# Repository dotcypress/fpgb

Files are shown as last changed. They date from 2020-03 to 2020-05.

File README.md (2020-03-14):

# Forth Programmable Breadboard

🚧 Work in progress. Don't try this at home. 🚧

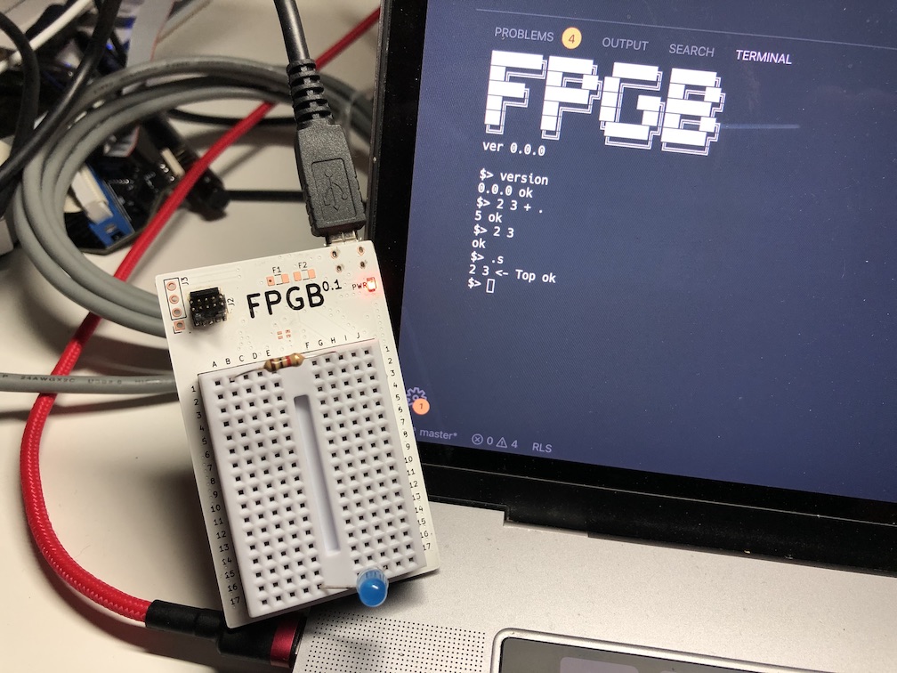
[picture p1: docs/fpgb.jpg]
Forth Programmable Breadboard


## Resources

- [Firmware](firmware/)
- [Schematics](docs/fpgb.pdf)
- [PCB(KiCad project)](pcb/)
- [Gerber files](docs/gerber)

## License

Licensed under either of

- Apache License, Version 2.0 ([LICENSE-APACHE](LICENSE-APACHE) or
  http://www.apache.org/licenses/LICENSE-2.0)
- MIT license ([LICENSE-MIT](LICENSE-MIT) or http://opensource.org/licenses/MIT)

at your option.

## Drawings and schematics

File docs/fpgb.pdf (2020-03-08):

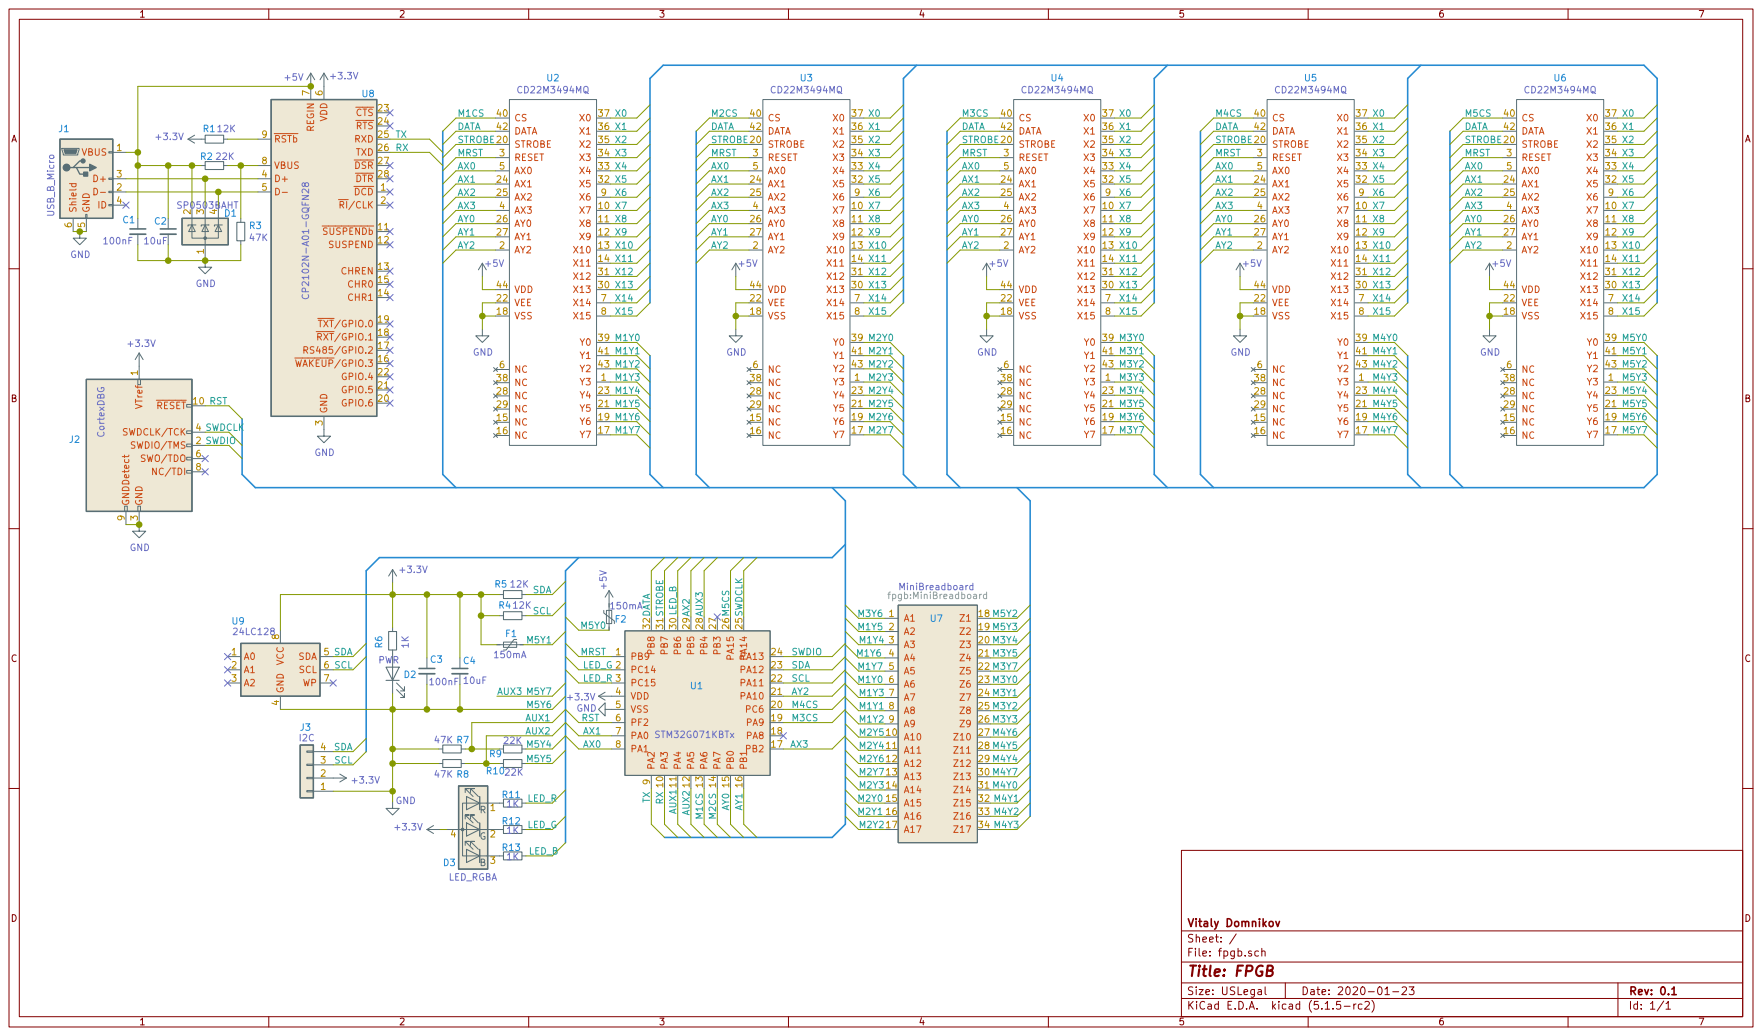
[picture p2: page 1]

7 VBUS 8 RSTb 9 U8 CP2102N-A01-GQFN28 VTref 1 RESET 10 SWDIO/TMS 2 GND

4D1 SP0503BAHT DCD 1 SUSPENDb 11 SUSPEND 12 CHREN 13 CHR1 14 CHR0 15 WAKEUP/GPIO.3 16 RS485/GPIO.2 17 RXT/GPIO.1 18 TXT/GPIO.0 19 RI/CLK 2 GPIO.6 20 GPIO.5 21 GPIO.4 22 CTS 23 RTS 24 RXD 25 TXD 26 DSR 27 DTR 28 GND

3 SWDCLK/TCK 4 SWO/TDO 6 NC/TDI 8 GNDDetect 9

4 SDA 5 SCL 6 WP 7 VCC

D Date: 2020-01-23 KiCad E.D.A. kicad (5.1.5-rc2)
File: fpgb.sch Sheet: / Vitaly Domnikov

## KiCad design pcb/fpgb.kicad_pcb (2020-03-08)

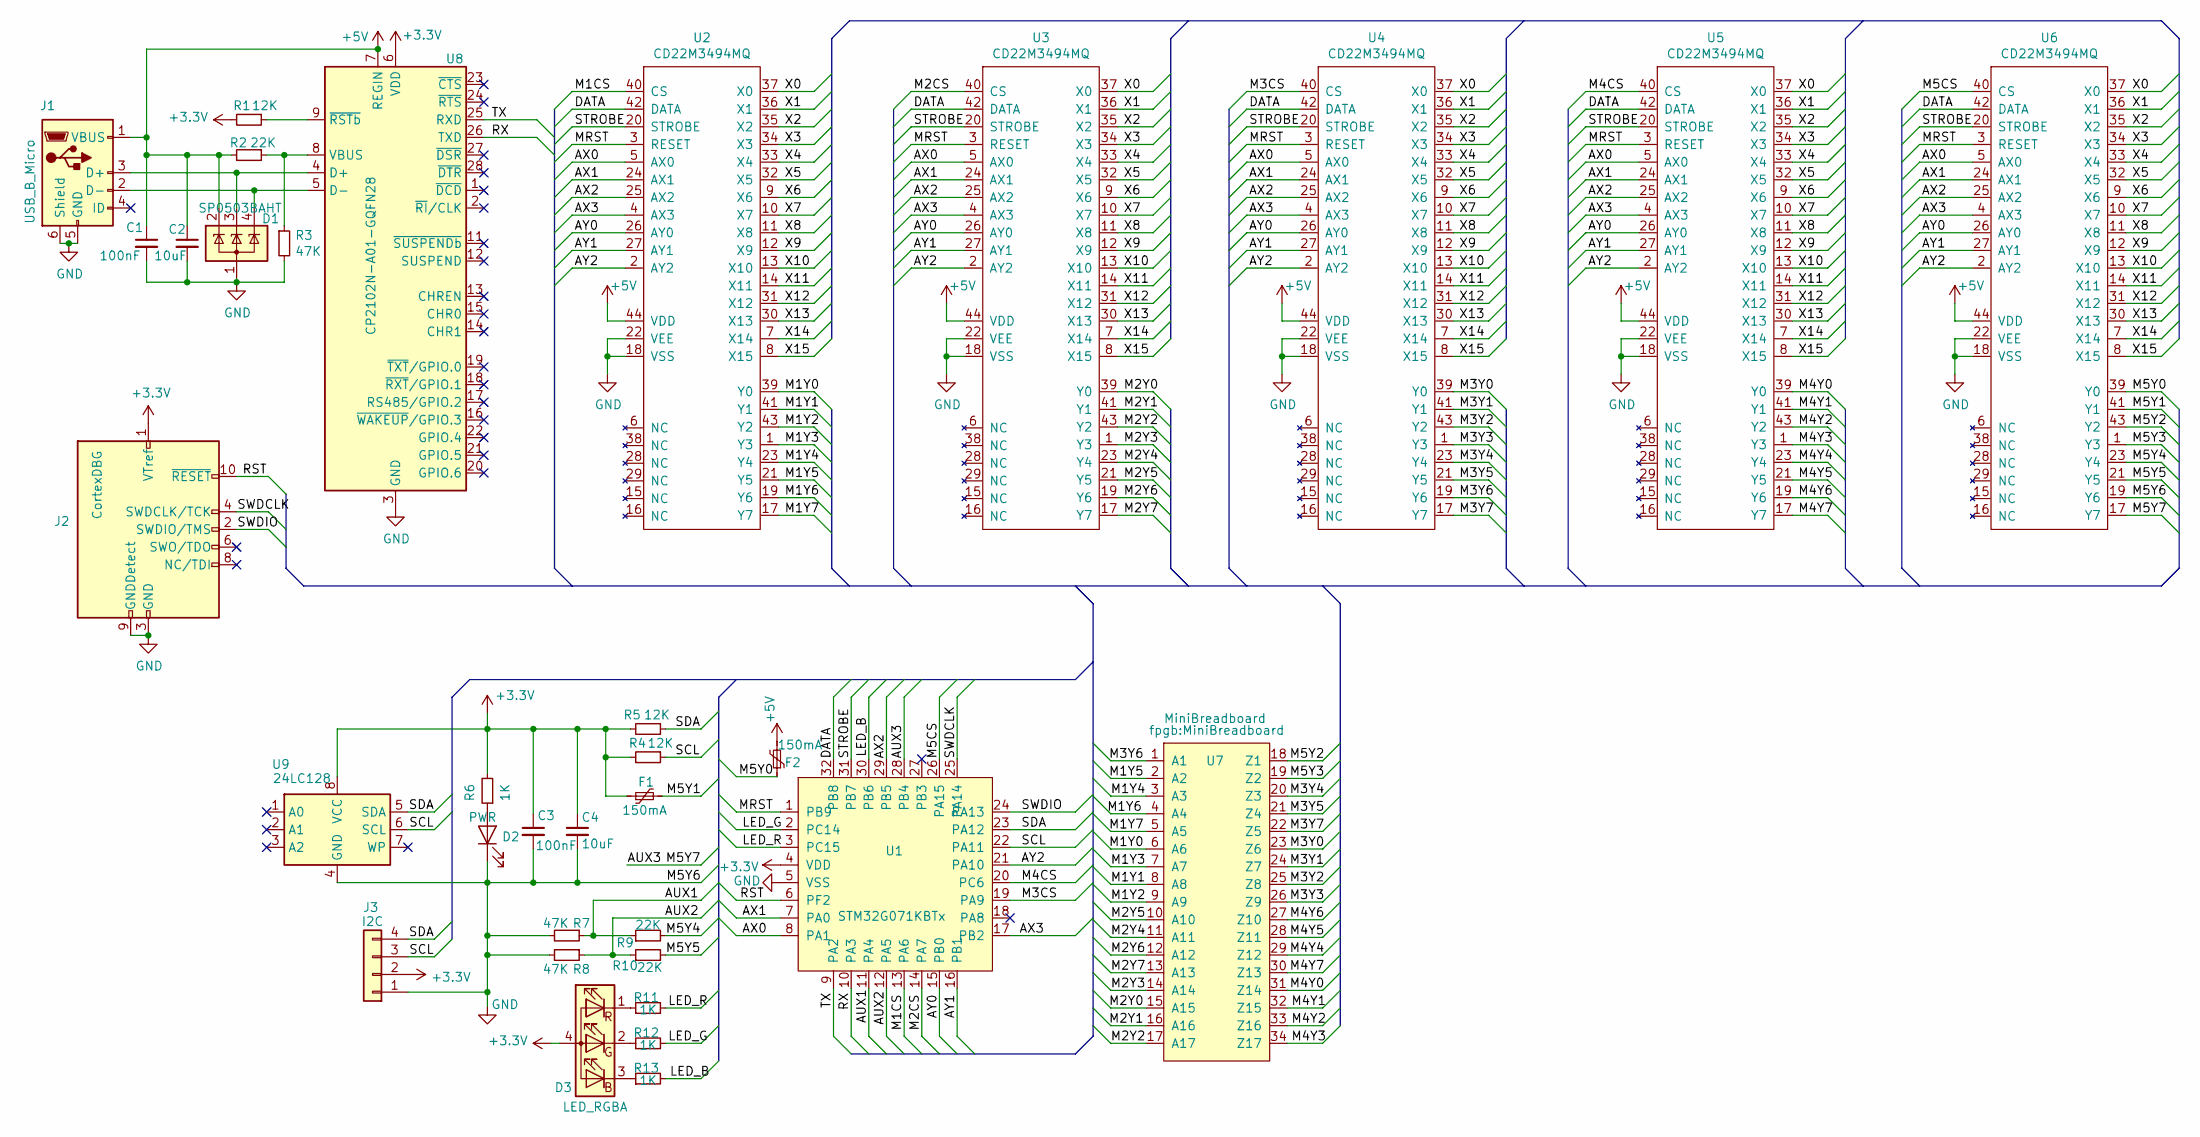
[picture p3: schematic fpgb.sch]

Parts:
C1, C3: 100nF; C_0603_1608Metric
C2, C4: 10uF; C_0603_1608Metric
D1: SP0503BAHT; SOT-143
D2: PWR; LED_0603_1608Metric
D3: LED_RGBA; LED_RGB_0606
F1, F2: 150mA; Fuse_1206_3216Metric
J1: USB_B_Micro; USB_Micro-B_Amphenol_10103594-0001LF_Horizontal
J2: CortexDBG; PinHeader_2x05_P1.27mm_Vertical_SMD
J3: I2C; PinSocket_1x04_P2.54mm_Vertical
R1, R4, R5: 12K; R_0603_1608Metric
R2, R9, R10: 22K; R_0603_1608Metric
R3, R7, R8: 47K; R_0603_1608Metric
R6, R11, R12, R13: 1K; R_0603_1608Metric
U1: STM32G071KBTx; LQFP-32_7x7mm_P0.8mm
U2, U3, U4, U5, U6: CD22M3494MQ; PLCC-44_16.6x16.6mm_P1.27mm
U7: MiniBreadboard
U8: CP2102N-A01-GQFN28; QFN-28-1EP_5x5mm_P0.5mm_EP3.35x3.35mm
U9: 24LC128; SOIC-8-1EP_3.9x4.9mm_P1.27mm_EP2.514x3.2mm

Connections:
+3V3: C3.1, C4.1, D3.4 (A), F1.1, J2.1 (VTref), J3.2, R1.2, R4.2, R5.2, R6.2, U1.4 (VDD), U8.6 (VDD), U9.8 (VCC)
+5V: C1.1, C2.1, D1.2 (K), F2.2, J1.1 (VBUS), R2.2, U2.44 (VDD), U3.44 (VDD), U4.44 (VDD), U5.44 (VDD), U6.44 (VDD), U8.7 (REGIN)
/AUX1: R7.1, R9.1, U1.11 (PA4)
/AUX2: R8.1, R10.1, U1.12 (PA5)
/AUX3: U1.28 (PB4), U6.17 (Y7)
/AX0: U1.8 (PA1), U2.5 (AX0), U3.5 (AX0), U4.5 (AX0), U5.5 (AX0), U6.5 (AX0)
/AX1: U1.7 (PA0), U2.24 (AX1), U3.24 (AX1), U4.24 (AX1), U5.24 (AX1), U6.24 (AX1)
/AX2: U1.29 (PB5), U2.25 (AX2), U3.25 (AX2), U4.25 (AX2), U5.25 (AX2), U6.25 (AX2)
/AX3: U1.17 (PB2), U2.4 (AX3), U3.4 (AX3), U4.4 (AX3), U5.4 (AX3), U6.4 (AX3)
/AY0: U1.15 (PB0), U2.26 (AY0), U3.26 (AY0), U4.26 (AY0), U5.26 (AY0), U6.26 (AY0)
/AY1: U1.16 (PB1), U2.27 (AY1), U3.27 (AY1), U4.27 (AY1), U5.27 (AY1), U6.27 (AY1)
/AY2: U1.21 (PA10), U2.2 (AY2), U3.2 (AY2), U4.2 (AY2), U5.2 (AY2), U6.2 (AY2)
/DATA: U1.32 (PB8), U2.42 (DATA), U3.42 (DATA), U4.42 (DATA), U5.42 (DATA), U6.42 (DATA)
/LED_B: R13.2, U1.30 (PB6)
/LED_G: R12.2, U1.2 (PC14)
/LED_R: R11.2, U1.3 (PC15)
/M1CS: U1.13 (PA6), U2.40 (CS)
/M1Y0: U2.39 (Y0), U7.6 (A6)
/M1Y1: U2.41 (Y1), U7.8 (A8)
/M1Y2: U2.43 (Y2), U7.9 (A9)
/M1Y3: U2.1 (Y3), U7.7 (A7)
/M1Y4: U2.23 (Y4), U7.3 (A3)
/M1Y5: U2.21 (Y5), U7.2 (A2)
/M1Y6: U2.19 (Y6), U7.4 (A4)
/M1Y7: U2.17 (Y7), U7.5 (A5)
/M2CS: U1.14 (PA7), U3.40 (CS)
/M2Y0: U3.39 (Y0), U7.15 (A15)
/M2Y1: U3.41 (Y1), U7.16 (A16)
/M2Y2: U3.43 (Y2), U7.17 (A17)
/M2Y3: U3.1 (Y3), U7.14 (A14)
/M2Y4: U3.23 (Y4), U7.11 (A11)
/M2Y5: U3.21 (Y5), U7.10 (A10)
/M2Y6: U3.19 (Y6), U7.12 (A12)
/M2Y7: U3.17 (Y7), U7.13 (A13)
/M3CS: U1.19 (PA9), U4.40 (CS)
/M3Y0: U4.39 (Y0), U7.23 (Z6)
/M3Y1: U4.41 (Y1), U7.24 (Z7)
/M3Y2: U4.43 (Y2), U7.25 (Z8)
/M3Y3: U4.1 (Y3), U7.26 (Z9)
/M3Y4: U4.23 (Y4), U7.20 (Z3)
/M3Y5: U4.21 (Y5), U7.21 (Z4)
/M3Y6: U4.19 (Y6), U7.1 (A1)
/M3Y7: U4.17 (Y7), U7.22 (Z5)
/M4CS: U1.20 (PC6), U5.40 (CS)
/M4Y0: U5.39 (Y0), U7.31 (Z14)
/M4Y1: U5.41 (Y1), U7.32 (Z15)
/M4Y2: U5.43 (Y2), U7.33 (Z16)
/M4Y3: U5.1 (Y3), U7.34 (Z17)
/M4Y4: U5.23 (Y4), U7.29 (Z12)
/M4Y5: U5.21 (Y5), U7.28 (Z11)
/M4Y6: U5.19 (Y6), U7.27 (Z10)
/M4Y7: U5.17 (Y7), U7.30 (Z13)
/M5CS: U1.26 (PA15), U6.40 (CS)
/M5Y0: F2.1, U6.39 (Y0)
/M5Y1: F1.2, U6.41 (Y1)
/M5Y2: U6.43 (Y2), U7.18 (Z1)
/M5Y3: U6.1 (Y3), U7.19 (Z2)
/M5Y4: R9.2, U6.23 (Y4)
/M5Y5: R10.2, U6.21 (Y5)
/MRST: U1.1 (PB9), U2.3 (RESET), U3.3 (RESET), U4.3 (RESET), U5.3 (RESET), U6.3 (RESET)
/RST: J2.10 (~RESET~), U1.6 (PF2)
/RX: U1.10 (PA3), U8.26 (TXD)
/SCL: J3.3, R4.1, U1.22 (PA11), U9.6 (SCL)
/SDA: J3.4, R5.1, U1.23 (PA12), U9.5 (SDA)
/STROBE: U1.31 (PB7), U2.20 (STROBE), U3.20 (STROBE), U4.20 (STROBE), U5.20 (STROBE), U6.20 (STROBE)
/SWDCLK: J2.4 (SWDCLK/TCK), U1.25 (PA14)
/SWDIO: J2.2 (SWDIO/TMS), U1.24 (PA13)
/TX: U1.9 (PA2), U8.25 (RXD)
/X0: U2.37 (X0), U3.37 (X0), U4.37 (X0), U5.37 (X0), U6.37 (X0)
/X1: U2.36 (X1), U3.36 (X1), U4.36 (X1), U5.36 (X1), U6.36 (X1)
/X2: U2.35 (X2), U3.35 (X2), U4.35 (X2), U5.35 (X2), U6.35 (X2)
/X3: U2.34 (X3), U3.34 (X3), U4.34 (X3), U5.34 (X3), U6.34 (X3)
/X4: U2.33 (X4), U3.33 (X4), U4.33 (X4), U5.33 (X4), U6.33 (X4)
/X5: U2.32 (X5), U3.32 (X5), U4.32 (X5), U5.32 (X5), U6.32 (X5)
/X6: U2.9 (X6), U3.9 (X6), U4.9 (X6), U5.9 (X6), U6.9 (X6)
/X7: U2.10 (X7), U3.10 (X7), U4.10 (X7), U5.10 (X7), U6.10 (X7)
/X8: U2.11 (X8), U3.11 (X8), U4.11 (X8), U5.11 (X8), U6.11 (X8)
/X9: U2.12 (X9), U3.12 (X9), U4.12 (X9), U5.12 (X9), U6.12 (X9)
/X10: U2.13 (X10), U3.13 (X10), U4.13 (X10), U5.13 (X10), U6.13 (X10)
/X11: U2.14 (X11), U3.14 (X11), U4.14 (X11), U5.14 (X11), U6.14 (X11)
/X12: U2.31 (X12), U3.31 (X12), U4.31 (X12), U5.31 (X12), U6.31 (X12)
/X13: U2.30 (X13), U3.30 (X13), U4.30 (X13), U5.30 (X13), U6.30 (X13)
/X14: U2.7 (X14), U3.7 (X14), U4.7 (X14), U5.7 (X14), U6.7 (X14)
/X15: U2.8 (X15), U3.8 (X15), U4.8 (X15), U5.8 (X15), U6.8 (X15)
GND: C1.2, C2.2, C3.2, C4.2, D1.1 (A), D2.1 (K), J1.5 (GND), J1.6 (Shield), J2.3 (GND), J2.5 (GND), J2.9 (GNDDetect), J3.1, R3.2, R7.2, R8.2, U1.5 (VSS), U2.18 (VSS), U2.22 (VEE), U3.18 (VSS), U3.22 (VEE), U4.18 (VSS), U4.22 (VEE), U5.18 (VSS), U5.22 (VEE), U6.18 (VSS), U6.19 (Y6), U6.22 (VEE), U8.3 (GND), U8.29 (GND), U9.4 (GND)
unnamed: D1.3 (K), J1.3 (D+), U8.4 (D+)
unnamed: D1.4 (K), J1.2 (D-), U8.5 (D-)
unnamed: D2.2 (A), R6.1
unnamed: D3.1 (RK), R11.1
unnamed: D3.2 (GK), R12.1
unnamed: D3.3 (BK), R13.1
unnamed: R1.1, U8.9 (~RSTb)
unnamed: R2.1, R3.1, U8.8 (VBUS)

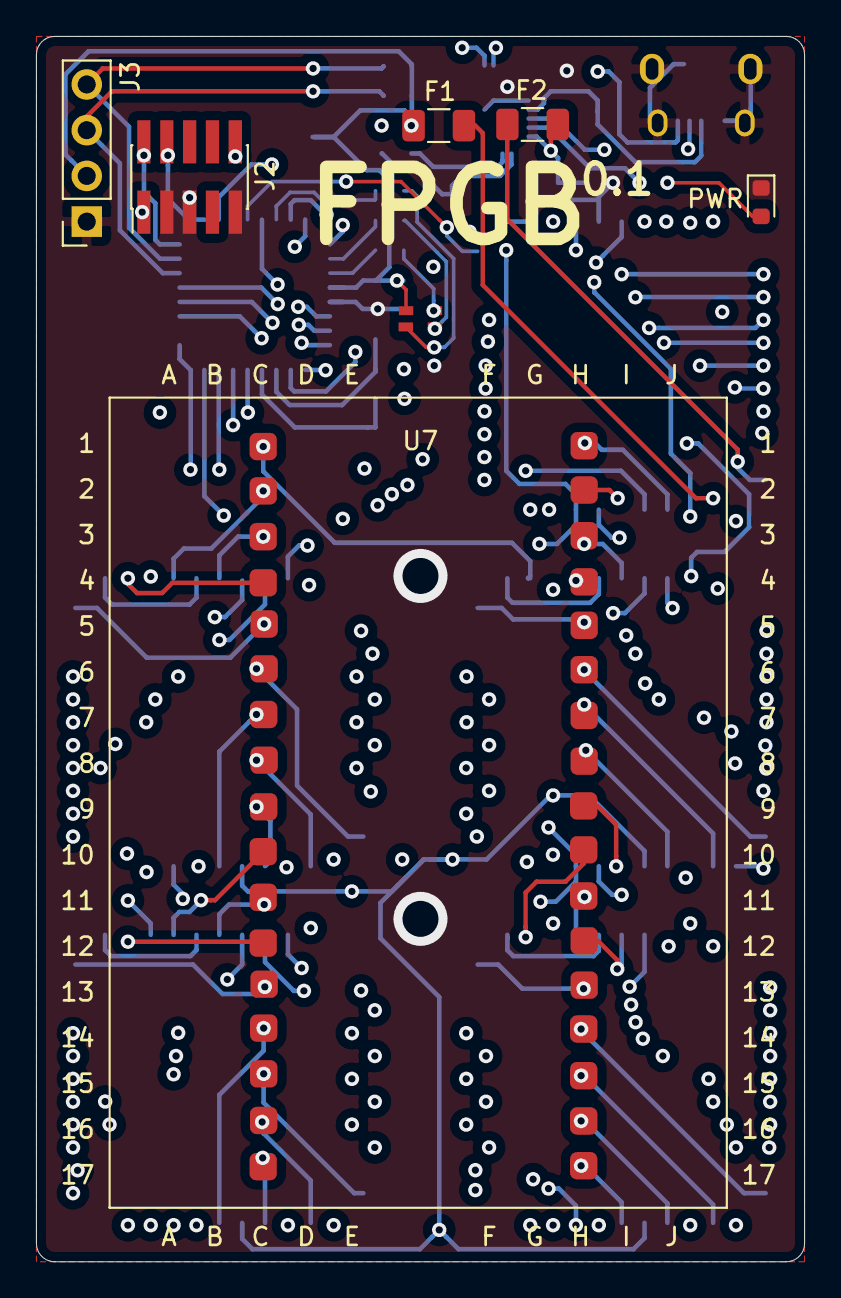
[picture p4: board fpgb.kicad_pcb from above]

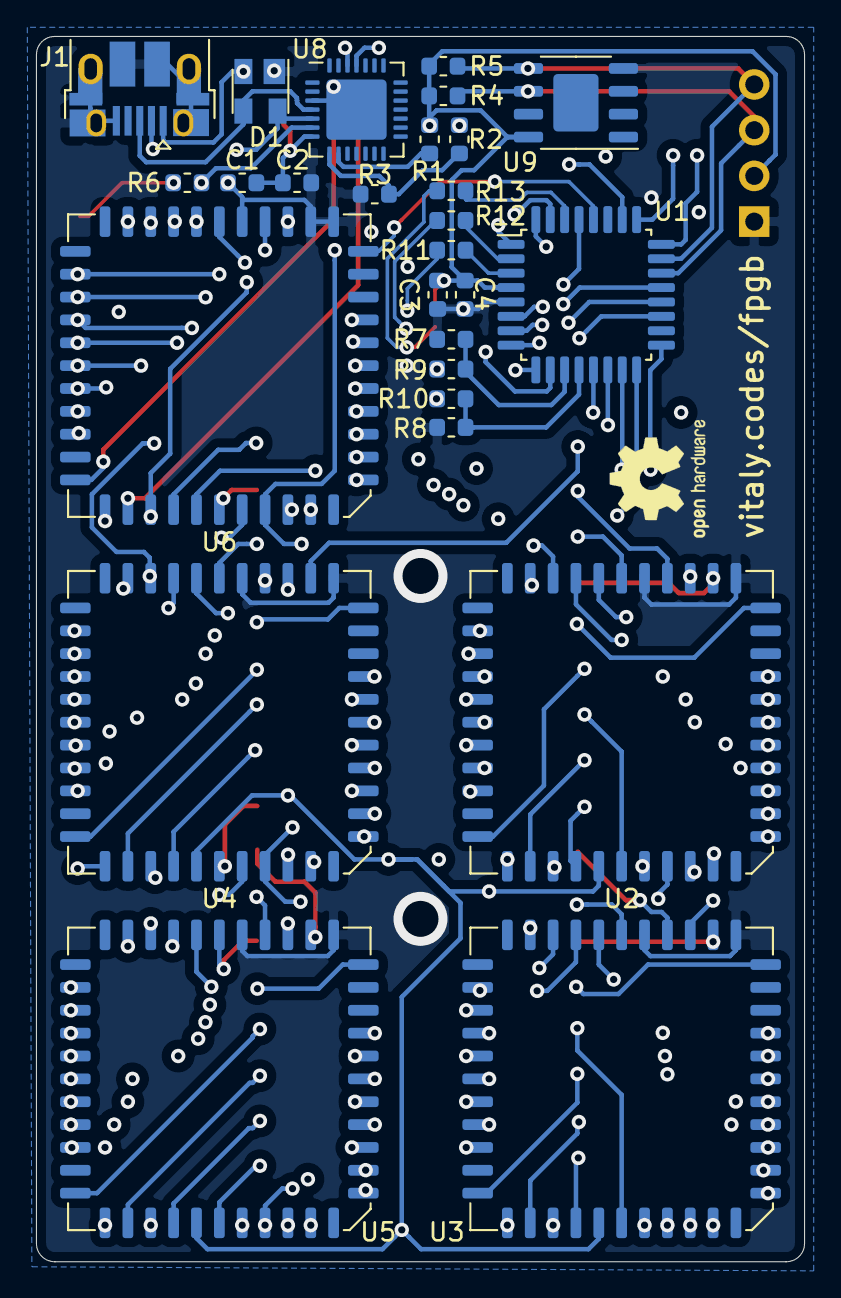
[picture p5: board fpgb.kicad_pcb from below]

Board: 4 copper layers, 42.7 x 68.1 mm, 34 parts (27 on the bottom side), 93 nets.

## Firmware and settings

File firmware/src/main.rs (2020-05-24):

#![no_std]
#![no_main]
extern crate panic_semihosting;
extern crate rtfm;
extern crate stm32g0xx_hal as hal;
extern crate wire4;

mod breadboard;
mod config;
mod eeprom;
mod fpgb;
mod matrix;
mod shell;

use config::*;
use fpgb::FPGB;
use hal::analog::adc;
use hal::i2c;
use hal::prelude::*;
use hal::serial;
use rtfm::app;

#[app(device = hal::stm32, peripherals = true)]
const APP: () = {
    struct Resources {
        fpgb: FPGB,
        led_timer: LedTimer,
    }

    #[init]
    fn init(ctx: init::Context) -> init::LateResources {
        let mut rcc = ctx.device.RCC.freeze(hal::rcc::Config::pll());

        let mut vm_delay = ctx.device.TIM15.delay(&mut rcc);
        let eeprom_delay = ctx.device.TIM3.delay(&mut rcc);
        let matrix_delay = ctx.device.TIM2.delay(&mut rcc);

        let port_a = ctx.device.GPIOA.split(&mut rcc);
        let port_b = ctx.device.GPIOB.split(&mut rcc);
        let port_c = ctx.device.GPIOC.split(&mut rcc);

        let mut led_timer = ctx.device.TIM17.timer(&mut rcc);
        led_timer.start(ANIMATION_FREQ);
        led_timer.listen();

        let mut adc = ctx.device.ADC.constrain(&mut rcc);
        adc.set_sample_time(adc::SampleTime::T_80);
        adc.set_precision(adc::Precision::B_12);
        let adc_pin = port_a.pa5.into_analog();

        let mut dac = ctx.device.DAC.constrain(port_a.pa4, &mut rcc);
        dac.calibrate(&mut vm_delay);
        dac.enable();

        let serial_cgf = serial::Config::default().baudrate(115_200.bps());
        let mut serial = ctx
            .device
            .USART2
            .usart(port_a.pa2, port_a.pa3, serial_cgf, &mut rcc)
            .expect("Failed to constrain serial port");
        serial.listen(serial::Event::Rxne);

        let i2c = ctx.device.I2C2.i2c(
            port_a.pa12.into_open_drain_output(),
            port_a.pa11.into_open_drain_output(),
            i2c::Config::new(1.mhz()),
            &mut rcc,
        );

        let mut store = EepromStore::new(EepromAdapter::new(i2c, eeprom_delay));
        if store.open().is_err() {
            store.create().expect("Store fail");
        };

        let reset = port_b.pb9.into_push_pull_output();
        let strobe = port_b.pb7.into_push_pull_output();
        let data = port_b.pb8.into_push_pull_output();

        let ax0 = port_a.pa1.into_push_pull_output();
        let ax1 = port_a.pa0.into_push_pull_output();
        let ax2 = port_b.pb5.into_push_pull_output();
        let ax3 = port_b.pb2.into_push_pull_output();

        let ay0 = port_b.pb0.into_push_pull_output();
        let ay1 = port_b.pb1.into_push_pull_output();
        let ay2 = port_a.pa10.into_push_pull_output();

        let cs0 = port_a.pa6.into_push_pull_output();
        let cs1 = port_a.pa7.into_push_pull_output();
        let cs2 = port_a.pa9.into_push_pull_output();
        let cs3 = port_c.pc6.into_push_pull_output();
        let cs4 = port_a.pa15.into_push_pull_output();

        let matrix = SwitchMatrix::new(
            matrix_delay,
            reset,
            strobe,
            data,
            (ax0, ax1, ax2, ax3),
            (ay0, ay1, ay2),
            (cs0, cs1, cs2, cs3, cs4),
        );

        let mut fpgb = FPGB::new(vm_delay, serial, dac, adc, adc_pin, matrix, store);
        fpgb.reset().expect("Failed to reset breadboard");

        init::LateResources { fpgb, led_timer }
    }

    #[task(binds = USART2, resources = [fpgb])]
    fn serial_data(ctx: serial_data::Context) {
        ctx.resources.fpgb.poll_serial();
    }

    #[task(binds = TIM17, resources = [led_timer])]
    fn led_timer(ctx: led_timer::Context) {
        ctx.resources.led_timer.clear_irq();
    }

    #[idle(resources = [fpgb])]
    fn idle(mut ctx: idle::Context) -> ! {
        loop {
            ctx.resources.fpgb.lock(|fpgb| fpgb.spin());
        }
    }
};

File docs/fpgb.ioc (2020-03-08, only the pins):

Mcu.UserName=STM32G071KBTx
PA0.GPIO_Label=AX1
PA0.Signal=GPIO_Output
PA1.GPIO_Label=AX0
PA1.Signal=GPIO_Output
PA10.GPIO_Label=AY2
PA10.Signal=GPIO_Output
PA13.Signal=SYS_SWDIO
PA14-BOOT0.Signal=SYS_SWCLK
PA15.GPIO_Label=M5CS
PA15.Signal=GPIO_Output
PA2.Signal=USART2_TX
PA3.Signal=USART2_RX
PA4.Signal=COMP_DAC11_group
PA5.Signal=ADC1_IN5
PA6.GPIO_Label=M1CS
PA6.Signal=GPIO_Output
PA7.GPIO_Label=M2CS
PA7.Signal=GPIO_Output
PA9.GPIO_Label=M3CS
PA9.Signal=GPIO_Output
PB0.GPIO_Label=AY0
PB0.Signal=GPIO_Output
PB1.GPIO_Label=AY1
PB1.Signal=GPIO_Output
PB2.GPIO_Label=AX3
PB2.Signal=GPIO_Output
PB3.GPIO_Label=AUX3
PB3.Signal=GPIO_Output
PB5.GPIO_Label=AX2
PB5.Signal=GPIO_Output
PB6.GPIO_Label=LED_B
PB6.Signal=GPIO_Output
PB7.GPIO_Label=STROBE
PB7.Signal=GPIO_Output
PB8.GPIO_Label=DATA
PB8.Signal=GPIO_Output
PB9.GPIO_Label=MRST
PB9.Signal=GPIO_Output
PC6.GPIO_Label=M4CS
PC6.Signal=GPIO_Output

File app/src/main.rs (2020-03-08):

#[cfg(debug_assertions)]
use actix_files::NamedFile;
use actix_web::{web, App, Error, HttpRequest, HttpResponse, HttpServer, Result};
use actix_web_actors::ws;
use std::net::SocketAddr;
#[cfg(debug_assertions)]
use std::path::PathBuf;
use structopt::StructOpt;

mod bridge;

#[derive(Debug, StructOpt)]
struct Cli {
    #[structopt(
        short = "a",
        long = "addr",
        default_value = "127.0.0.1:8383",
        help = "Webserver address."
    )]
    addr: SocketAddr,
}

#[cfg(debug_assertions)]
fn index(req: HttpRequest) -> Result<NamedFile> {
    let filename: String = req
        .match_info()
        .query("filename")
        .parse()
        .expect("Failed to parse filename");
    let mut path: PathBuf = PathBuf::from("./static");
    if filename.is_empty() {
        path.push("index.html");
    } else {
        path.push(filename);
    }
    Ok(NamedFile::open(path)?)
}

#[cfg(not(debug_assertions))]
fn index(req: HttpRequest) -> HttpResponse {
    static ICON: &'static [u8] = include_bytes!("./../static/favicon.png");
    static HOME: &'static str = include_str!("./../static/index.html");
    static CSS: &'static str = include_str!("./../static/app.css");
    static JS: &'static str = include_str!("./../static/app.js");

    let filename = req
        .match_info()
        .query("filename")
        .parse::<String>()
        .expect("Failed to parse filename");

    match filename.as_ref() {
        "" | "index.html" => HttpResponse::Ok()
            .content_type("text/html; charset=utf-8")
            .body(HOME),
        "app.js" => HttpResponse::Ok()
            .content_type("text/javascript; charset=utf-8")
            .body(JS),
        "app.css" => HttpResponse::Ok().content_type("text/css").body(CSS),
        "favicon.png" => HttpResponse::Ok().content_type("image/png").body(ICON),
        _ => HttpResponse::NotFound().finish(),
    }
}

fn ws_bridge(req: HttpRequest, stream: web::Payload) -> Result<HttpResponse, Error> {
    ws::start(bridge::BridgeSession::new(), &req, stream)
}

fn main() {
    let cli = Cli::from_args();
    println!("http://{}", cli.addr);
    HttpServer::new(move || {
        App::new()
            .service(web::resource("/ws").to(ws_bridge))
            .route("/{filename:.*}", web::get().to(index))
    })
    .bind(cli.addr)
    .expect("Failed to bind to network interface")
    .run()
    .expect("Failed to start server");
}
